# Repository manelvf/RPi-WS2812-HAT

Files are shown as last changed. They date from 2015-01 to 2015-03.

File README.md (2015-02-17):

# RPi-WS2812-HAT
WS2812B intelligent RGB-LED 8x8 Matrix HAT (Hardware Attached on Top) for Raspberry Pi.

RPi-WS2812-HAT (http://www.watterott.com/en/RPi-WS2812-HAT)

## Shop
* [RPi-WS2812-HAT](http://www.watterott.com/en/RPi-WS2812-HAT)

## Features
* 64 WS2812 RGB-LED with built-in controller with serial interface
* Atmel ATtiny85 with [Micronucleus](https://github.com/micronucleus/micronucleus) USB Bootloader
* MicroUSB connector
* ID EEPROM
* [Raspberry Pi HAT](https://github.com/raspberrypi/hats) compatible

## Hardware and Software
* [Schematics + Layout](https://github.com/watterott/RPi-WS2812-HAT/tree/master/pcb)
* [Arduino and Raspberry Pi Examples](https://github.com/watterott/RPi-WS2812-HAT/tree/master/src)
* [Little Wire](http://littlewire.cc) can also be used on the ATtiny85.
* [FAQ (Frequently Asked Questions)](https://github.com/watterott/RPi-WS2812-HAT/blob/master/docu/FAQ.md)

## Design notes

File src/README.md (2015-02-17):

# Arduino Examples for ATtiny85
The examples can be compiled and uploaded using the Arduino IDE with Digistump or our ATtiny85 extension.

## Files
* [Arduino IDE v1.6](http://arduino.cc/en/Main/Software)
* Extensions
  * [ATtiny85](https://github.com/watterott/wattuino/tree/master/src/Arduino)
  * [Digistump](https://github.com/digistump/DigistumpArduino)
* [Micronucleus Windows Driver](https://github.com/watterott/wattuino/tree/master/src/Arduino/drivers/Micronucleus)
* [Libraries](https://github.com/watterott/Arduino-Libs)
  * [light_WS2812](https://github.com/watterott/Arduino-Libs/tree/master/light_WS2812)
  * [TinyWire](https://github.com/watterott/Arduino-Libs/tree/master/TinyWire)
* [Examples](https://github.com/watterott/RPi-WS2812-HAT/tree/master/src)

## Upload
* Open the example.
* Select under Tools->Board: **ATtiny85 (internal 16.5MHz)** or **Digispark (16.5MHz)**.
* Select Upload.
* When the compiling has finished and "Uploading..." is shown, unplug and plug back in the USB connector or press the reset switch to start the bootloader.
* Wait till the upload has finished and "Done uploading" is shown.

# Raspberry Pi Examples

* Upload the ```I2C_Slave.ino``` example to the ATtiny85 on the RPi-WS2812-HAT.

* Install i2c-tools and python-smbus:

    ```
    $ sudo apt-get install i2c-tools
    $ sudo apt-get install python-smbus
    ```

* Activate I2C device:

    ```
    $ sudo modprobe i2c_bcm2708 baudrate=400000
    $ sudo modprobe i2c-dev
    ```

* Test I2C bus:

    ```
    $ sudo i2cdetect -y 1
    ```

* Download and run the Python examples (Random.py, Fill.py...):

    ```
    $ wget https://github.com/watterott/RPi-WS2812-HAT/raw/master/src/Random.py
    $ sudo python Random.py
    ```

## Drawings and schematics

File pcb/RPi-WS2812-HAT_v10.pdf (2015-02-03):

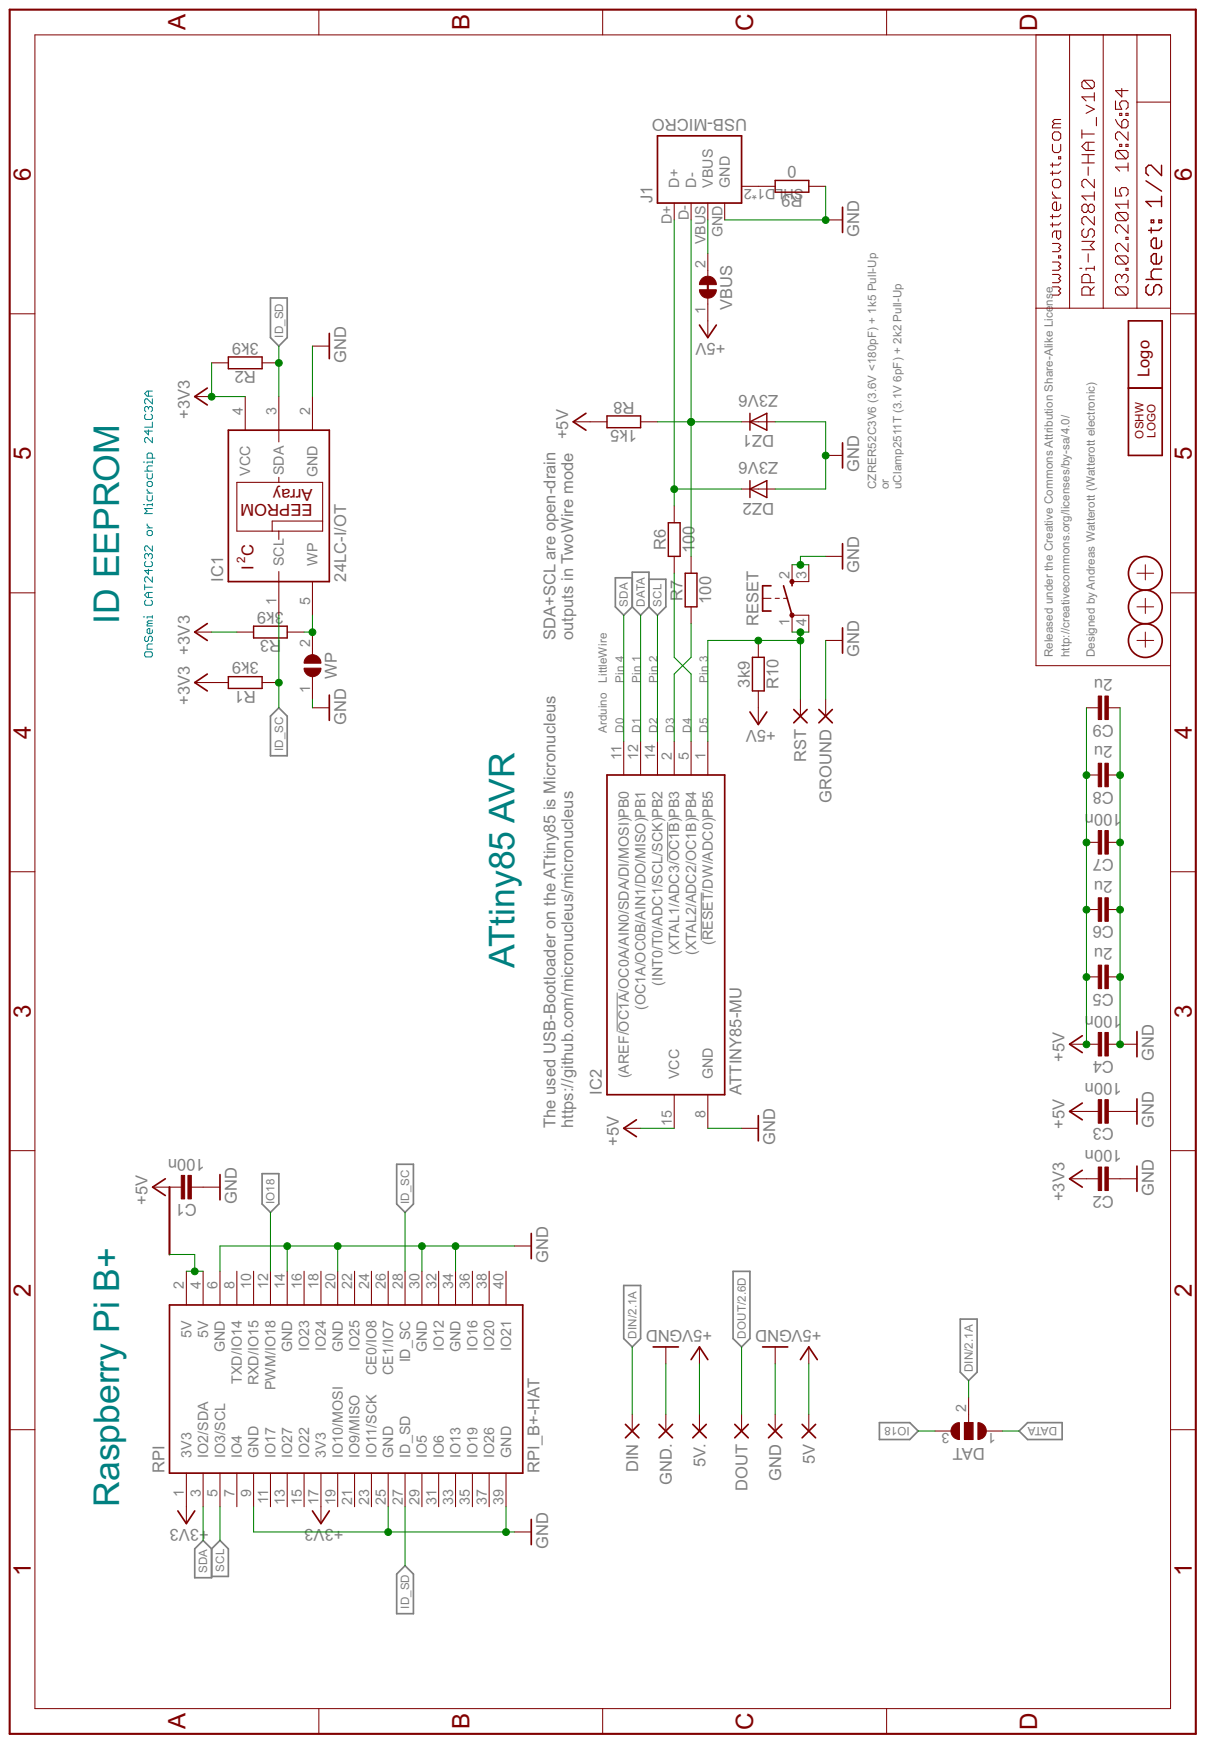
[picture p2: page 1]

GND 8 (XTAL2/ADC2/OC1B)PB4 5 (XTAL1/ADC3/OC1B)PB3 2 (INT0/T0/ADC1/SCL/SCK)PB2 14 (OC1A/OC0B/AIN1/DO/MISO)PB1 12 (AREF/OC1A/OC0A/AIN0/SDA/DI/MOSI)PB0 11 D+ D+ D- D- VBUS VBUS

Released under the Creative Commons Attribution Share-Alike License

Designed by Andreas Watterott (Watterott electronic)

http://creativecommons.org/licenses/by-sa/4.0/

Raspberry Pi B+ ID EEPROM

SDA+SCL are open-drain

outputs in TwoWire mode

The used USB-Bootloader on the ATtiny85 is Micronucleus

https://github.com/micronucleus/micronucleus

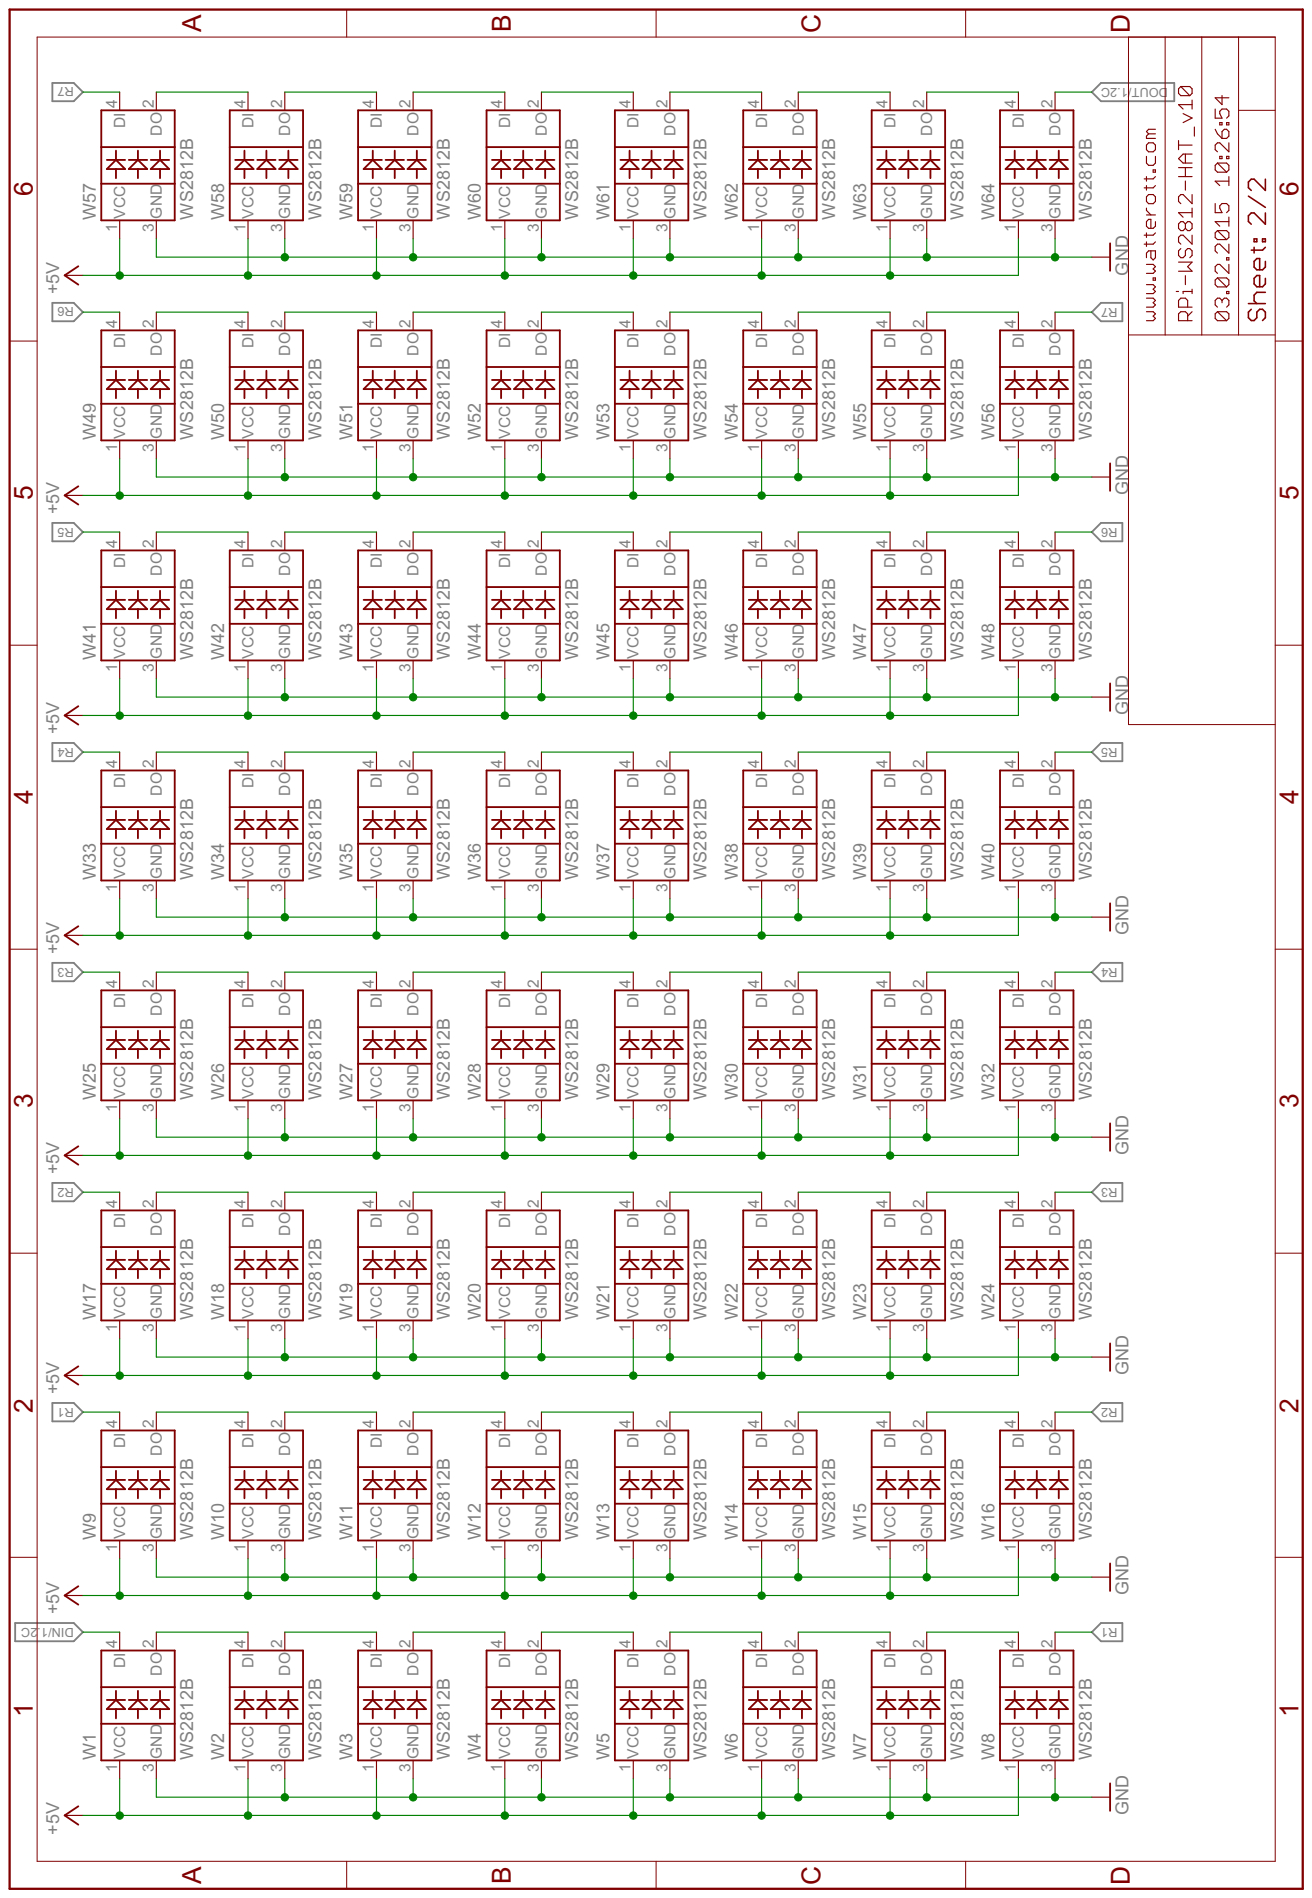
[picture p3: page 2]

GND GND GND GND GND GND GND

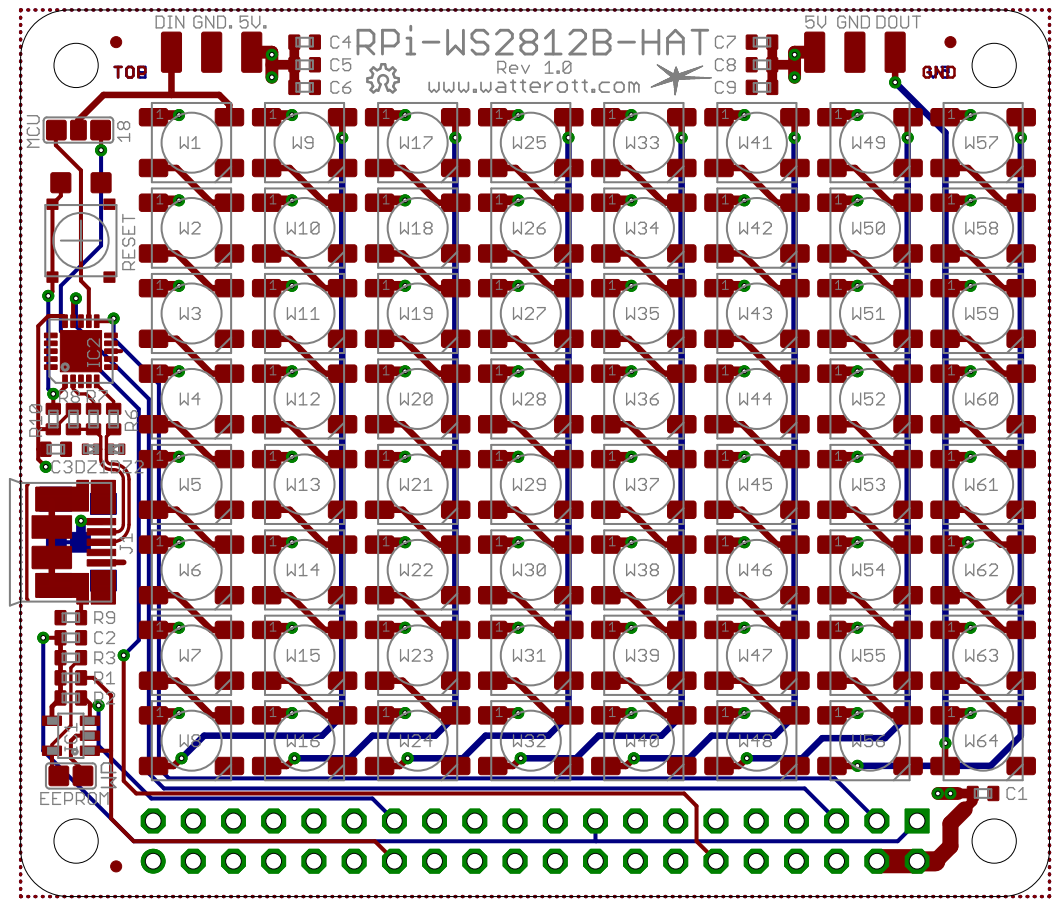
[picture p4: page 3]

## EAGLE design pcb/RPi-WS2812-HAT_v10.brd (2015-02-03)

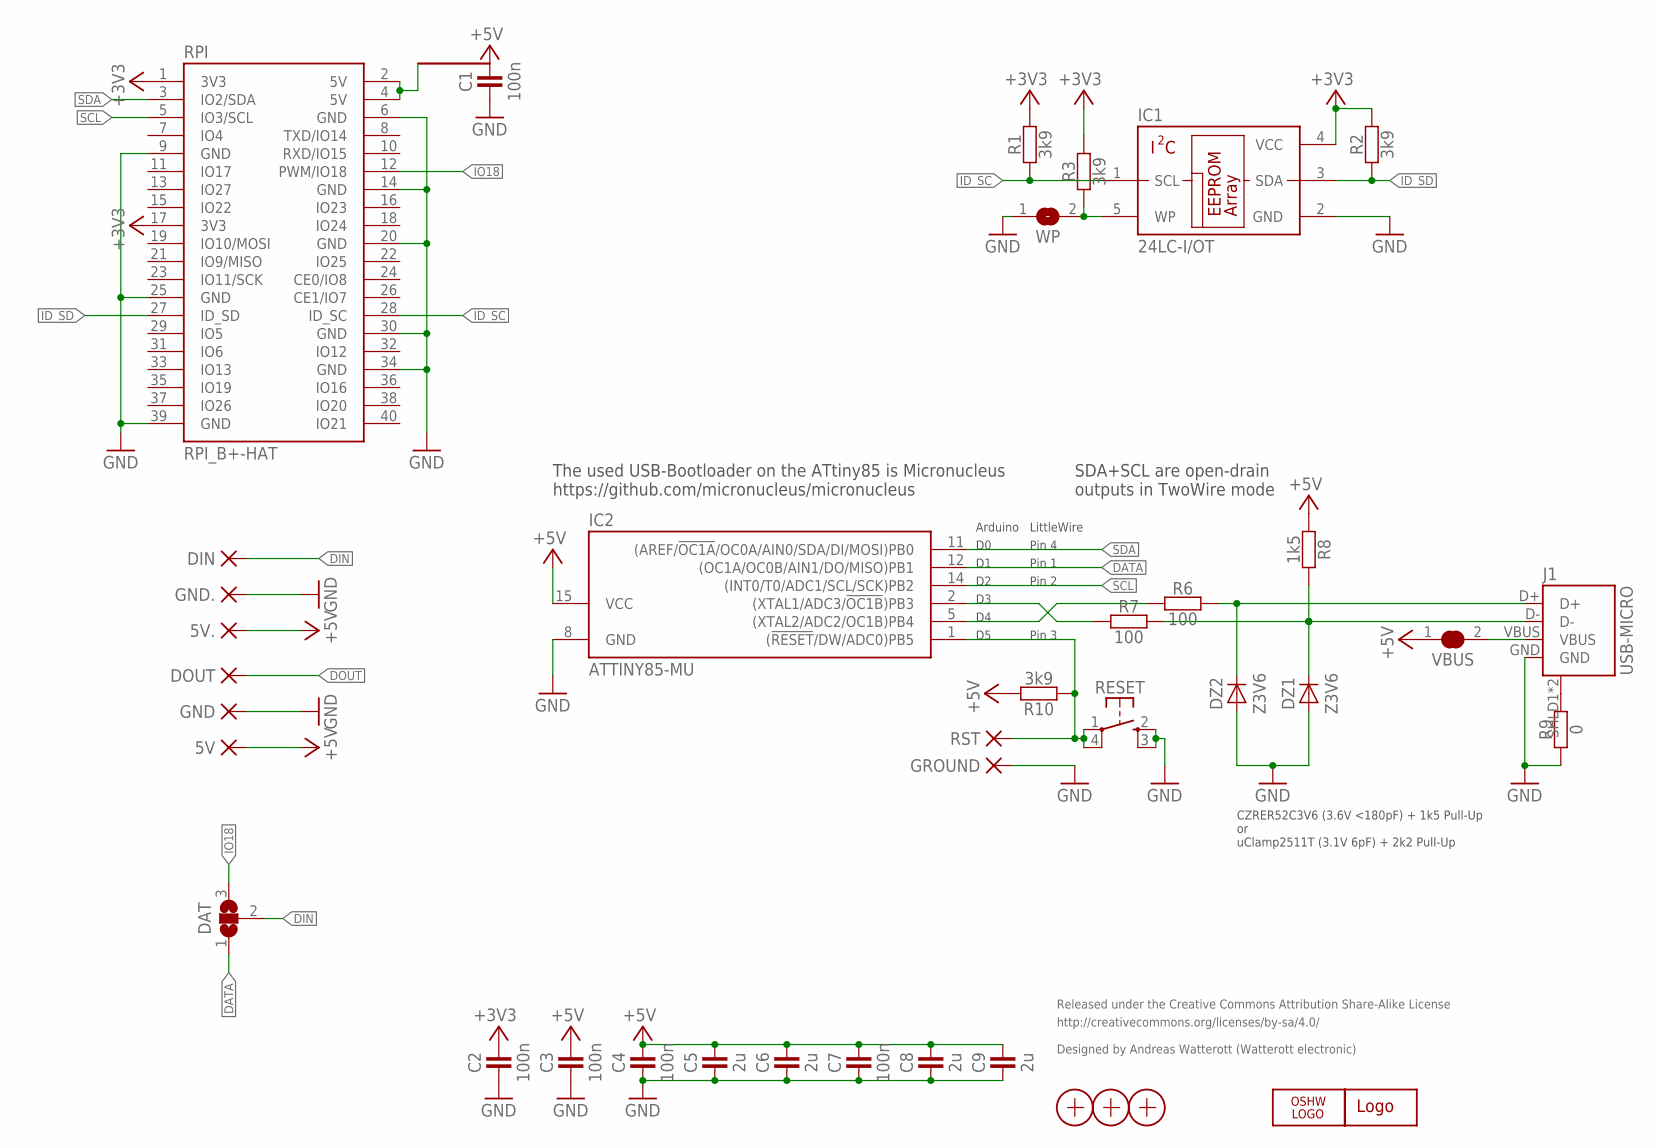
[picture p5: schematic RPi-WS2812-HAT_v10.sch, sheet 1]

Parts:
5V, 5V.: PAD-1.27X2.54_NC
C1, C2, C3, C4, C7: 100n; R0402
C5, C6, C8, C9: 2u; R0402
DAT: JUMPER3-0603
DIN: PAD-1.27X2.54_NC
DOUT: PAD-1.27X2.54_NC
DZ1, DZ2: Z3V6; SOD882
GND, GND.: PAD-1.27X2.54_NC
GROUND: PAD-1.27X1.27_NC
IC1: 24LC-I/OT; SOT23-5
IC2: ATTINY85-MU; QFN20-PAD
J1: USB-MICRO; USB-MICRO-10103594
LOGO1: LOGO-S_PLACE_S; SPARK_TPLACE_S
LOGO2: OSHW_LOGOX0070; OSHW_6X70
R1, R2, R3, R10: 3k9; R0402
R6, R7: 100; R0402
R8: 1k5; R0402
R9: 0; R0402
RESET: SW-TACTILE-TL3315; SW_TL3315N
RPI: RPI_B+-HAT; RPI-B+HAT
RST: PAD-1.27X1.27_NC
VBUS: JUMPER2-0603-NC; JUMPER2-0603_NC
WP: JUMPER2-0603-NC; JUMPER2-0603_NC
X1, X2, X3: PASSER-07; PASSER_07MM

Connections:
5V: RPI.2 (5V), RPI.4 (5V)
+3V3: C2.2, IC1.4 (VCC), R1.2, R2.2, R3.2, RPI.1 (3V3), RPI.17 (3V3)
+5V: 5V.1, 5V..1, C1.2, C3.2, C4.2, C5.2, C6.2, C7.2, C8.2, C9.2, IC2.15 (VCC), R8.1, R10.2, VBUS.1; also elsewhere on the board
D2_N: IC2.2 ((XTAL1/ADC3/!OC1B!)PB3), R7.1
D2_P: IC2.5 ((XTAL2/ADC2/OC1B)PB4), R6.1
DATA: DAT.1, IC2.12 ((OC1A/OC0B/AIN1/DO/MISO)PB1)
DIN: DAT.2, DIN.1; also elsewhere on the board
DOUT: DOUT.1; also elsewhere on the board
D_N: DZ1.C, J1.D-, R7.2, R8.2
D_P: DZ2.C, J1.D+, R6.2
GND: C1.1, C2.1, C3.1, C4.1, C5.1, C6.1, C7.1, C8.1, C9.1, DZ1.A, DZ2.A, GND.1, GND..1, GROUND.1, IC1.2 (GND), IC2.8 (GND), J1.GND, R9.1, RESET.2 (S1), RESET.3 (S2), RPI.6 (GND), RPI.9 (GND), RPI.14 (GND), RPI.20 (GND), RPI.25 (GND), RPI.30 (GND), RPI.34 (GND), RPI.39 (GND), WP.1; also elsewhere on the board
ID_SC: IC1.1 (SCL), R1.1, RPI.28 (ID_SC)
ID_SD: IC1.3 (SDA), R2.1, RPI.27 (ID_SD)
IO18: DAT.3, RPI.12 (PWM/IO18)
unnamed: J1.SHLD1 (SHIELD), J1.SHLD2 (SHIELD), R9.2
RST: IC2.1 ((!RESET!/DW/ADC0)PB5), R10.1, RESET.1, RESET.4 (P2), RST.1
SCL: IC2.14 ((INT0/T0/ADC1/SCL/SCK)PB2), RPI.5 (IO3/SCL)
SDA: IC2.11 ((AREF/!OC1A!/OC0A/AIN0/SDA/DI/MOSI)PB0), RPI.3 (IO2/SDA)
VBUS: J1.VBUS, VBUS.2
WP: IC1.5 (WP), R3.1, WP.2

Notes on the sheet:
Released under the Creative Commons Attribution Share-Alike License
http://creativecommons.org/licenses/by-sa/4.0/
Designed by Andreas Watterott (Watterott electronic)
The used USB-Bootloader on the ATtiny85 is Micronucleus https://github.com/micronucleus/micronucleus
CZRER52C3V6 (3.6V <180pF) + 1k5 Pull-Up or uClamp2511T (3.1V 6pF) + 2k2 Pull-Up
Pin 1
Pin 4
Pin 2
Pin 3
LittleWire
Arduino
SDA+SCL are open-drain outputs in TwoWire mode

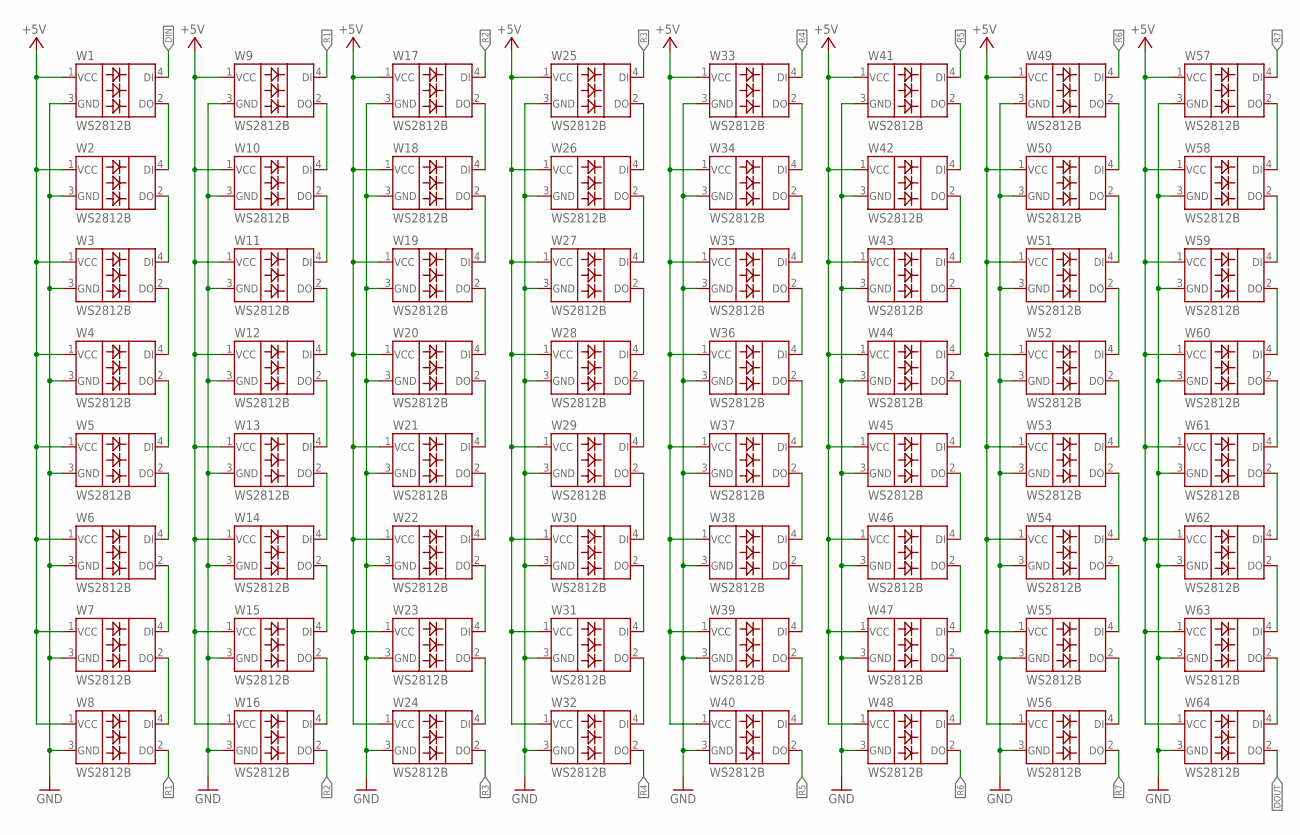
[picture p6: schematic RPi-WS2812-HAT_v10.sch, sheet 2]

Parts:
W1, W2, W3, W4, W5, W6, W7, W8, W9, W10, W11, W12, W13, W14, W15, W16, W17, W18, W19, W20, W21, W22, W23, W24, W25, W26, W27, W28, W29, W30, W31, W32, W33, W34, W35, W36, W37, W38, W39, W40, W41, W42, W43, W44, W45, W46, W47, W48, W49, W50, W51, W52, W53, W54, W55, W56, W57, W58, W59, W60, W61, W62, W63, W64: WS2812B

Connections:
+5V: W1.1 (VCC), W2.1 (VCC), W3.1 (VCC), W4.1 (VCC), W5.1 (VCC), W6.1 (VCC), W7.1 (VCC), W8.1 (VCC), W9.1 (VCC), W10.1 (VCC), W11.1 (VCC), W12.1 (VCC), W13.1 (VCC), W14.1 (VCC), W15.1 (VCC), W16.1 (VCC), W17.1 (VCC), W18.1 (VCC), W19.1 (VCC), W20.1 (VCC), W21.1 (VCC), W22.1 (VCC), W23.1 (VCC), W24.1 (VCC), W25.1 (VCC), W26.1 (VCC), W27.1 (VCC), W28.1 (VCC), W29.1 (VCC), W30.1 (VCC), W31.1 (VCC), W32.1 (VCC), W33.1 (VCC), W34.1 (VCC), W35.1 (VCC), W36.1 (VCC), W37.1 (VCC), W38.1 (VCC), W39.1 (VCC), W40.1 (VCC), W41.1 (VCC), W42.1 (VCC), W43.1 (VCC), W44.1 (VCC), W45.1 (VCC), W46.1 (VCC), W47.1 (VCC), W48.1 (VCC), W49.1 (VCC), W50.1 (VCC), W51.1 (VCC), W52.1 (VCC), W53.1 (VCC), W54.1 (VCC), W55.1 (VCC), W56.1 (VCC), W57.1 (VCC), W58.1 (VCC), W59.1 (VCC), W60.1 (VCC), W61.1 (VCC), W62.1 (VCC), W63.1 (VCC), W64.1 (VCC); also elsewhere on the board
DIN: W1.4 (DI); also elsewhere on the board
DOUT: W64.2 (DO); also elsewhere on the board
GND: W1.3 (GND), W2.3 (GND), W3.3 (GND), W4.3 (GND), W5.3 (GND), W6.3 (GND), W7.3 (GND), W8.3 (GND), W9.3 (GND), W10.3 (GND), W11.3 (GND), W12.3 (GND), W13.3 (GND), W14.3 (GND), W15.3 (GND), W16.3 (GND), W17.3 (GND), W18.3 (GND), W19.3 (GND), W20.3 (GND), W21.3 (GND), W22.3 (GND), W23.3 (GND), W24.3 (GND), W25.3 (GND), W26.3 (GND), W27.3 (GND), W28.3 (GND), W29.3 (GND), W30.3 (GND), W31.3 (GND), W32.3 (GND), W33.3 (GND), W34.3 (GND), W35.3 (GND), W36.3 (GND), W37.3 (GND), W38.3 (GND), W39.3 (GND), W40.3 (GND), W41.3 (GND), W42.3 (GND), W43.3 (GND), W44.3 (GND), W45.3 (GND), W46.3 (GND), W47.3 (GND), W48.3 (GND), W49.3 (GND), W50.3 (GND), W51.3 (GND), W52.3 (GND), W53.3 (GND), W54.3 (GND), W55.3 (GND), W56.3 (GND), W57.3 (GND), W58.3 (GND), W59.3 (GND), W60.3 (GND), W61.3 (GND), W62.3 (GND), W63.3 (GND), W64.3 (GND); also elsewhere on the board
unnamed: W1.2 (DO), W2.4 (DI)
unnamed: W2.2 (DO), W3.4 (DI)
unnamed: W3.2 (DO), W4.4 (DI)
unnamed: W4.2 (DO), W5.4 (DI)
unnamed: W5.2 (DO), W6.4 (DI)
unnamed: W6.2 (DO), W7.4 (DI)
unnamed: W7.2 (DO), W8.4 (DI)
unnamed: W9.2 (DO), W10.4 (DI)
unnamed: W10.2 (DO), W11.4 (DI)
unnamed: W11.2 (DO), W12.4 (DI)
unnamed: W12.2 (DO), W13.4 (DI)
unnamed: W13.2 (DO), W14.4 (DI)
unnamed: W15.2 (DO), W16.4 (DI)
unnamed: W14.2 (DO), W15.4 (DI)
unnamed: W23.2 (DO), W24.4 (DI)
unnamed: W22.2 (DO), W23.4 (DI)
unnamed: W21.2 (DO), W22.4 (DI)
unnamed: W20.2 (DO), W21.4 (DI)
unnamed: W19.2 (DO), W20.4 (DI)
unnamed: W18.2 (DO), W19.4 (DI)
unnamed: W17.2 (DO), W18.4 (DI)
unnamed: W25.2 (DO), W26.4 (DI)
unnamed: W26.2 (DO), W27.4 (DI)
unnamed: W28.2 (DO), W29.4 (DI)
unnamed: W27.2 (DO), W28.4 (DI)
unnamed: W29.2 (DO), W30.4 (DI)
unnamed: W31.2 (DO), W32.4 (DI)
unnamed: W30.2 (DO), W31.4 (DI)
unnamed: W55.2 (DO), W56.4 (DI)
unnamed: W41.2 (DO), W42.4 (DI)
unnamed: W33.2 (DO), W34.4 (DI)
unnamed: W34.2 (DO), W35.4 (DI)
unnamed: W42.2 (DO), W43.4 (DI)
unnamed: W43.2 (DO), W44.4 (DI)
unnamed: W35.2 (DO), W36.4 (DI)
unnamed: W36.2 (DO), W37.4 (DI)
unnamed: W37.2 (DO), W38.4 (DI)
unnamed: W39.2 (DO), W40.4 (DI)
unnamed: W47.2 (DO), W48.4 (DI)
unnamed: W46.2 (DO), W47.4 (DI)
unnamed: W54.2 (DO), W55.4 (DI)
unnamed: W38.2 (DO), W39.4 (DI)
unnamed: W45.2 (DO), W46.4 (DI)
unnamed: W44.2 (DO), W45.4 (DI)
unnamed: W52.2 (DO), W53.4 (DI)
unnamed: W53.2 (DO), W54.4 (DI)
unnamed: W51.2 (DO), W52.4 (DI)
unnamed: W50.2 (DO), W51.4 (DI)
unnamed: W49.2 (DO), W50.4 (DI)
unnamed: W63.2 (DO), W64.4 (DI)
unnamed: W62.2 (DO), W63.4 (DI)
unnamed: W61.2 (DO), W62.4 (DI)
unnamed: W60.2 (DO), W61.4 (DI)
unnamed: W59.2 (DO), W60.4 (DI)
unnamed: W57.2 (DO), W58.4 (DI)
unnamed: W58.2 (DO), W59.4 (DI)
R1: W8.2 (DO), W9.4 (DI)
R2: W16.2 (DO), W17.4 (DI)
R3: W24.2 (DO), W25.4 (DI)
R4: W32.2 (DO), W33.4 (DI)
R5: W40.2 (DO), W41.4 (DI)
R6: W48.2 (DO), W49.4 (DI)
R7: W56.2 (DO), W57.4 (DI)

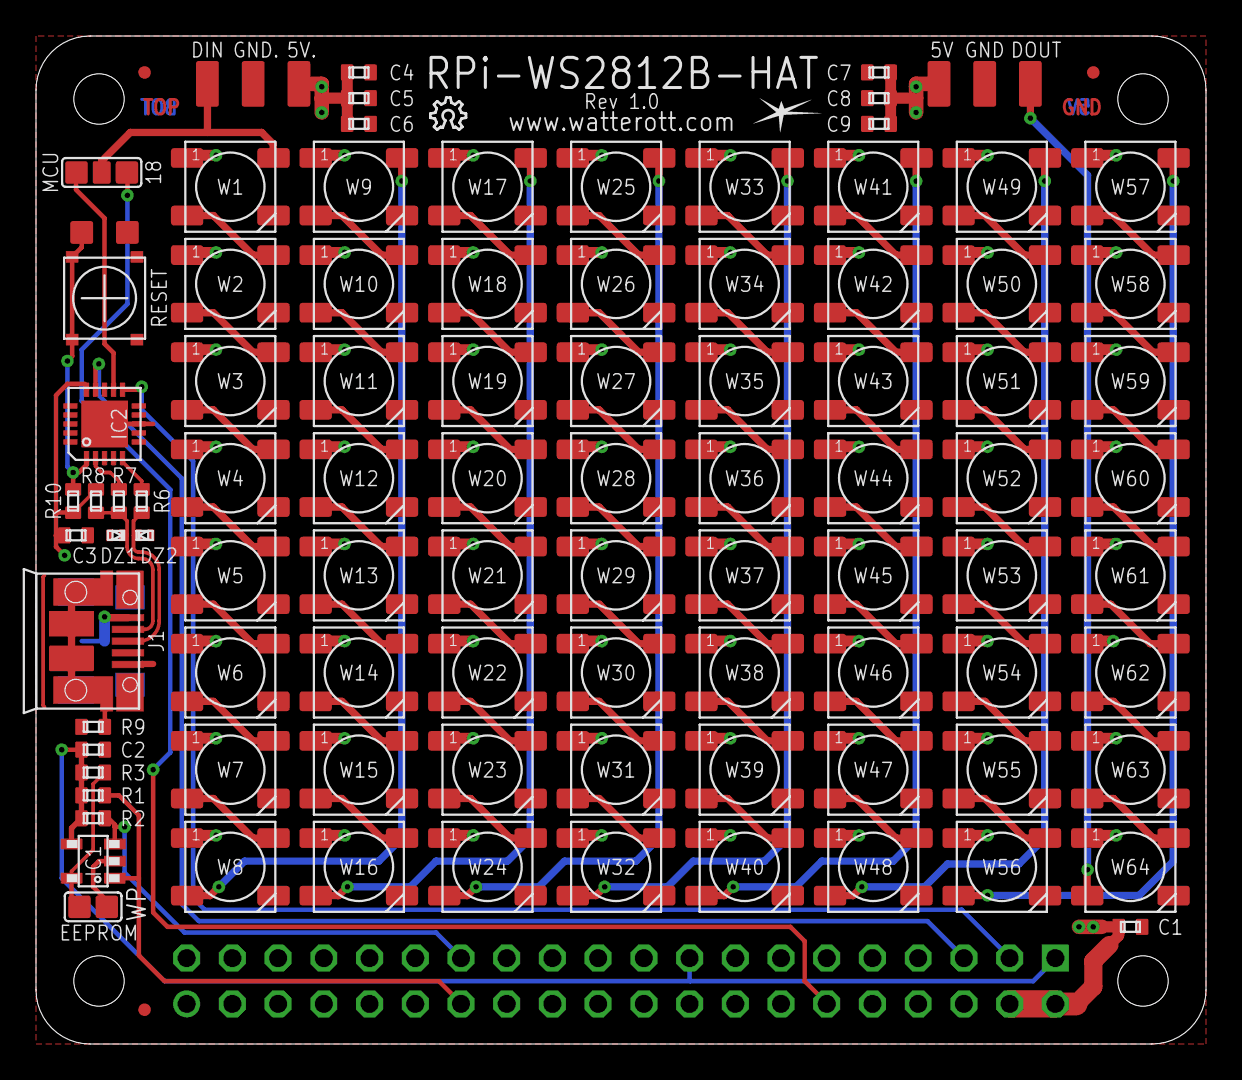
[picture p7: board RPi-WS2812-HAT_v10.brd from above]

Board: 2 copper layers, 65.0 x 56.0 mm, 104 parts (1 on the bottom side), 83 nets.

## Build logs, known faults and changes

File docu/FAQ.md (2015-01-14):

# Frequently Asked Questions

## How much power does the LED-Matrix need?
The Matrix consists of 64 RGB LEDs and each LED needs about 60mA (3 * 20mA) at full brightness.
Therefore the maximum current is 64 * 0.06A = 3.8A.

## How is the ATtiny85 connected to the RPi?
The ATtiny85 is connected via SDA+SCL (I2C) to the Raspberry Pi.

## Can the Raspberry Pi control the WS2812 LEDs directly?
For direct control of the WS2812 LEDs from the Raspberry Pi have a look at the examples from: [626Pilot](https://github.com/626Pilot/RaspberryPi-NeoPixel-WS2812) and [jgarff](https://github.com/jgarff/rpi_ws281x).
The jumper next to the reset switch has to be closed to position 18.
Then the data input of the first WS2812 LED is connected to GPIO18 of the Raspberry Pi.

## How to flash/update the ID EEPROM?
The EEPROM on the HAT can be updated as follows.
Before the update the **WP** jumper next to the EEPROM has to be closed.

* Install [EEPROM utils](https://github.com/raspberrypi/hats/tree/master/eepromutils):
    ```
    $ git clone https://github.com/raspberrypi/hats
    $ cd hats/eepromutils
    $ make
    $ chmod +x eepflash.sh
    ```

* Generate EEPROM data:
    ```
    $ wget https://github.com/watterott/RPi-WS2812-HAT/raw/master/docu/rpi-ws2812-hat.txt
    $ ./eepmake rpi-ws2812-hat.txt rpi-ws2812-hat.eep
    ```

* Update EEPROM:
    ```
    $ sudo ./eepflash.sh -w -t=24c32 -f=rpi-ws2812-hat.eep
    ```

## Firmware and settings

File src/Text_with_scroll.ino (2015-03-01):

/*
  RPi-WS2812-HAT Text with Scroll Example

  Based on original Text.ino example
  Modified by: Manel Vilar
 */

#include <WS2812.h>
//#include <avr/pgmspace.h>

#define DATAPIN     1 //digital output pin (data input of LEDs)
#define LEDCOUNT   64 //number of LEDs to drive
#define INTENSITY 100 //light intensity

WS2812 LED(LEDCOUNT);

byte intensity=2;
byte sign=0;

const byte font_data[] PROGMEM =
{
  0x00,0x00,0x00,0x00,0x00,0x00,0x00,0x00, // 0x20
  0x30,0x78,0x78,0x30,0x30,0x00,0x30,0x00, // 0x21
  0x6C,0x6C,0x6C,0x00,0x00,0x00,0x00,0x00, // 0x22
  0x6C,0x6C,0xFE,0x6C,0xFE,0x6C,0x6C,0x00, // 0x23
  0x30,0x7C,0xC0,0x78,0x0C,0xF8,0x30,0x00, // 0x24
  0x00,0xC6,0xCC,0x18,0x30,0x66,0xC6,0x00, // 0x25
  0x38,0x6C,0x38,0x76,0xDC,0xCC,0x76,0x00, // 0x26
  0x60,0x60,0xC0,0x00,0x00,0x00,0x00,0x00, // 0x27
  0x18,0x30,0x60,0x60,0x60,0x30,0x18,0x00, // 0x28
  0x60,0x30,0x18,0x18,0x18,0x30,0x60,0x00, // 0x29
  0x00,0x66,0x3C,0xFF,0x3C,0x66,0x00,0x00, // 0x2A
  0x00,0x30,0x30,0xFC,0x30,0x30,0x00,0x00, // 0x2B
  0x00,0x00,0x00,0x00,0x00,0x70,0x30,0x60, // 0x2C
  0x00,0x00,0x00,0xFC,0x00,0x00,0x00,0x00, // 0x2D
  0x00,0x00,0x00,0x00,0x00,0x30,0x30,0x00, // 0x2E
  0x06,0x0C,0x18,0x30,0x60,0xC0,0x80,0x00, // 0x2F
  0x78,0xCC,0xDC,0xFC,0xEC,0xCC,0x78,0x00, // 0x30
  0x30,0xF0,0x30,0x30,0x30,0x30,0xFC,0x00, // 0x31
  0x78,0xCC,0x0C,0x38,0x60,0xCC,0xFC,0x00, // 0x32
  0x78,0xCC,0x0C,0x38,0x0C,0xCC,0x78,0x00, // 0x33
  0x1C,0x3C,0x6C,0xCC,0xFE,0x0C,0x0C,0x00, // 0x34
  0xFC,0xC0,0xF8,0x0C,0x0C,0xCC,0x78,0x00, // 0x35
  0x38,0x60,0xC0,0xF8,0xCC,0xCC,0x78,0x00, // 0x36
  0xFC,0xCC,0x0C,0x18,0x30,0x60,0x60,0x00, // 0x37
  0x78,0xCC,0xCC,0x78,0xCC,0xCC,0x78,0x00, // 0x38
  0x78,0xCC,0xCC,0x7C,0x0C,0x18,0x70,0x00, // 0x39
  0x00,0x00,0x30,0x30,0x00,0x30,0x30,0x00, // 0x3A
  0x00,0x00,0x30,0x30,0x00,0x70,0x30,0x60, // 0x3B
  0x18,0x30,0x60,0xC0,0x60,0x30,0x18,0x00, // 0x3C
  0x00,0x00,0xFC,0x00,0xFC,0x00,0x00,0x00, // 0x3D
  0x60,0x30,0x18,0x0C,0x18,0x30,0x60,0x00, // 0x3E
  0x78,0xCC,0x0C,0x18,0x30,0x00,0x30,0x00, // 0x3F
  0x7C,0xC6,0xDE,0xDE,0xDE,0xC0,0x78,0x00, // 0x40
  0x30,0x78,0xCC,0xCC,0xFC,0xCC,0xCC,0x00, // 0x41
  0xFC,0x66,0x66,0x7C,0x66,0x66,0xFC,0x00, // 0x42
  0x3C,0x66,0xC0,0xC0,0xC0,0x66,0x3C,0x00, // 0x43
  0xFC,0x6C,0x66,0x66,0x66,0x6C,0xFC,0x00, // 0x44
  0xFE,0x62,0x68,0x78,0x68,0x62,0xFE,0x00, // 0x45
  0xFE,0x62,0x68,0x78,0x68,0x60,0xF0,0x00, // 0x46
  0x3C,0x66,0xC0,0xC0,0xCE,0x66,0x3E,0x00, // 0x47
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
};

void setup()
{
  //init LEDs
  LED.setOutput(DATAPIN);
  //LED.setColorOrderRGB(); //uncomment for RGB color order
  //LED.setColorOrderBRG(); //uncomment for BRG color order
  LED.setColorOrderGRB(); //ucomment for GRB color order (default)
}

void write_ch(char c, char t, cRGB fg, cRGB bg, int offset, byte start_x)
{
  uint_least16_t pos, pos2;
  uint_least8_t data, data2, data3, mask;
  uint_least8_t i, j, width, height;
  const uint_least8_t *ptr PROGMEM;
  const uint_least8_t *ptr2 PROGMEM;\
  const uint_least8_t *tptr PROGMEM;\


  if((c < 0x20) || (c > 0x7F))
  {
    return;
  }

  pos = (c-0x20)*(8*8/8); //8x8 font
  ptr = &font_data[pos];

  pos2 = (t-0x20)*(8*8/8); //8x8 font
  ptr2 = &font_data[pos2];

  byte x, x2;
  for(byte y=0; y < 8; y++)
  {
    data = pgm_read_byte(ptr++);
    data >>=1; //offset 1 pixel to left

    x = start_x;
    for(mask=(1<<(offset-1)); mask!=0; mask>>=1, x++)
    {      
      if(data & mask)
      {
        LED.set_crgb_at((x*8)+y, fg); //set character on pixel
      }
      else
      {
        LED.set_crgb_at((x*8)+y, bg); //set character off pixel
      }
    }
    
    data2 = pgm_read_byte(ptr2++);
    data2 >>=1; //offset 1 pixel to left
    
    x2 = offset;
    for(mask=(1<<(8-1)); x2<9; mask>>=1, x2++)
    {      
      if(data2 & mask)
      {
        LED.set_crgb_at((x2*8)+y, fg); //set character on pixel
      }
      else
      {
        LED.set_crgb_at((x2*8)+y, bg); //set character off pixel
      }
    }

  }
}

void write_s(char *s, cRGB fg, cRGB bg, int ms)
{
  int offset;
  char *t;

  t = s;
  *t++;

  while(*s)
  {
    delay(50);
    for (offset = 8; offset > 0; offset--) {

      if (*t) {
        write_ch(*s, *t, fg, bg, offset, 0);
      }
      LED.sync(); //send the values to the LEDs

      delay(ms); //wait
    }
    *s++;
    *t++;
  }
  write_ch(' ', ' ', fg, bg, 0, 0); //clear after last letter
}

void loop()
{
  cRGB fg, bg;

  // Customize the color for each run here
  fg.r = random(0, 100);
  fg.g = random(0, 100);
  fg.b = random(0, 100);

  bg.r = 0;
  bg.g = 0;
  bg.b = 0;

  // last parameter is delay in ms for each letter
  write_s("Hello, World!", fg, bg, 150);
  delay(1000);
}

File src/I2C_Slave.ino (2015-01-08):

/*
  RPi-WS2812-HAT I2C Slave Example
  
  I2C Address: 0x20
  
  Data:
    Set one LED at 0...63
      [0...63] [rrr] [ggg] [bbb]
    Set all LEDs (64 LEDs x 24bit color)
      [254] [rrr] [ggg] [bbb] ... [rrr] [ggg] [bbb]
    Set all LEDs off
      [255]
 */

#include <WS2812.h>
#include <TinyWireS.h>

#define I2C_SLAVE_ADDR 0x20 //7-bit address

#define DATAPIN     1 //digital output pin (data input of LEDs)
#define LEDCOUNT   64 //number of LEDs to drive
#define INTENSITY 100 //light intensity

WS2812 LED(LEDCOUNT);

volatile byte state=0, sync=0;
volatile unsigned long last_data=0;

void reset(void)
{
  //flush buffers
  TinyWireS.begin(I2C_SLAVE_ADDR); 

  state = 0;
  sync  = 0;

  //switch off LEDs
  for(byte i=0; i < LEDCOUNT; i++)
  {
    cRGB value = {0,0,0};
    LED.set_crgb_at(i, value);
  }
  LED.sync();
}

void requestEvent()
{  
  TinyWireS.send(0x00); //return 0
}

void receiveEvent(uint8_t size)
{
  byte r;
  static cRGB color;
  static byte led_pos=0, block=0;

  last_data = millis();

  if(size > 32) //buffer overflow, TWI_RX_BUFFER_SIZE=32
  {
    reset();
    return;
  }

  while(size)
  {
    r = TinyWireS.receive();
    size--;
    if(state == 0) //new block
    {
      if(r == 0xFF) //clear
      {
        for(byte i=0; i < LEDCOUNT; i++)
        {
          cRGB value = {0,0,0};
          LED.set_crgb_at(i, value);
        }
        sync = 1;
      }
      if(r == 0xFE) //receive LEDCOUNT
      {
        state++;
        led_pos = 0;
        block   = 1;
      }
      else if(r < LEDCOUNT)
      {
        state++;
        led_pos = r;
        block   = 0;
      }
    }
    else if(state == 1) //red value
    {
      state++;
      color.r = r;
    }
    else if(state == 2) //green value
    {
      state++;
      color.g = r;
    }
    else if(state == 3) //blue value
    {
      color.b = r;
      LED.set_crgb_at(led_pos++, color);
      if(led_pos >= LEDCOUNT)
      {
        led_pos = 0;
        state   = 0;
        sync    = 1;
      }
      else if(block != 0)
      {
        state = 1;
      }
      else
      {
        state = 0;
        sync  = 1;
      }
    }
  }
}

void setup()
{
  //init LEDs
  LED.setOutput(DATAPIN);
  //LED.setColorOrderRGB(); //uncomment for RGB color order
  //LED.setColorOrderBRG(); //uncomment for BRG color order
  LED.setColorOrderGRB(); //ucomment for GRB color order (default)

  //init I2C
  TinyWireS.begin(I2C_SLAVE_ADDR);
  TinyWireS.onReceive(receiveEvent);
  TinyWireS.onRequest(requestEvent);

  //switch off LEDs
  reset();
}

void loop()
{
  TinyWireS_stop_check();

  if(sync != 0)
  {
    sync = 0;
    LED.sync();
  }

  if(state != 0) //receiving data
  {
    unsigned long ms = millis();
    if((ms-last_data) > 500) //reset I2C after 500ms inactivity
    {
      last_data = ms;
      state = 0;
      sync  = 1;
      //reset();
    }
  }
}

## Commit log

2015-01-01 added layout and schematics
    [RPi-WS2812-HAT_v10.brd, RPi-WS2812-HAT_v10.sch]
2015-01-08 updated layout
    [RPi-WS2812-HAT_v10.brd]
2015-02-03 updated schematics
    [RPi-WS2812-HAT_v10.brd, RPi-WS2812-HAT_v10.sch]
